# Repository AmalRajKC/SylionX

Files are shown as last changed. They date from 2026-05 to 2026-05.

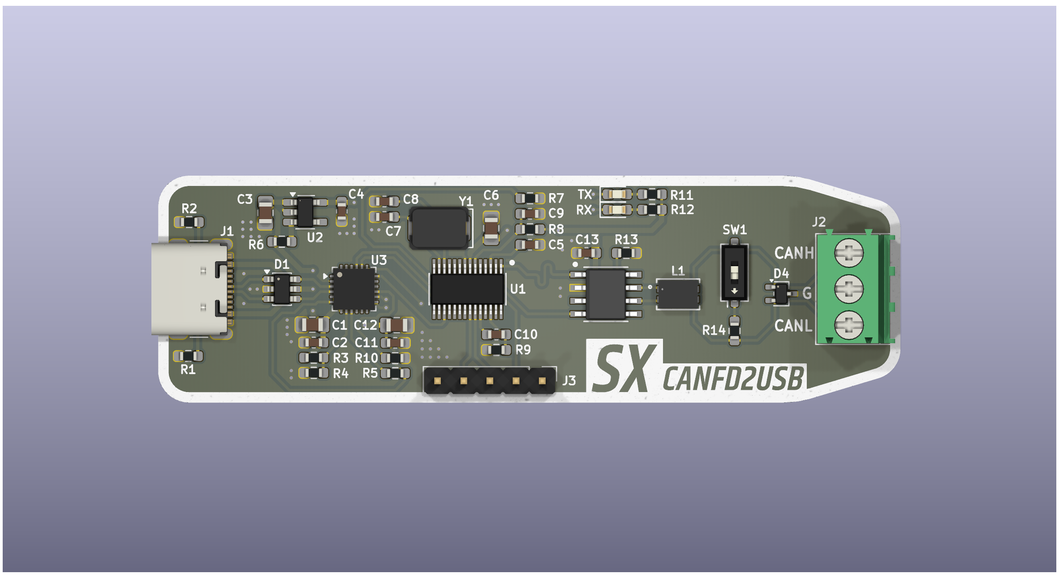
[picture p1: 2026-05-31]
CANFD2USB_Hardware/CANFDtoUSB_V1/CANFDtoUSB_V1.png

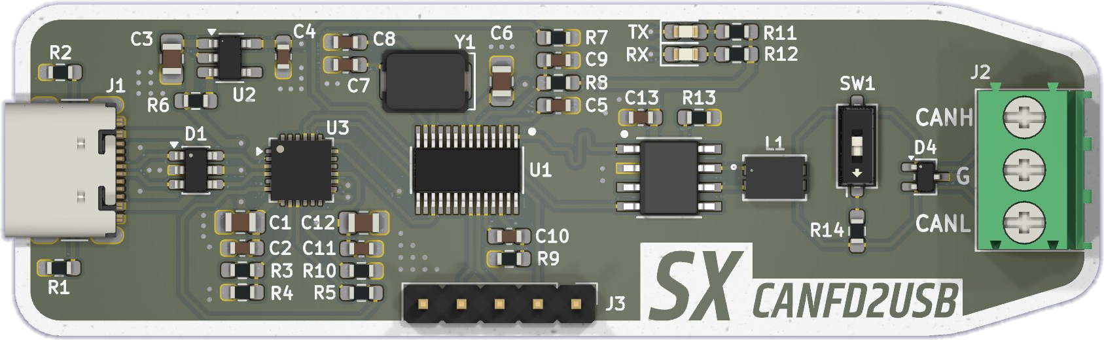
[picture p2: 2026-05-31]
CANFD2USB_Hardware/CANFDtoUSB_V1/CANFDtoUSB_V1nobg.png

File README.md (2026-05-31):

# SylionX — CANFD2USB




An open source USB to CAN FD adapter for real-time CAN bus monitoring, 
diagnostics, and frame injection.

## Repository Structure

| Folder | Contents | License |
|---|---|---|
| `CANFD2USB_Hardware` | KiCad schematics, PCB layout, BOM, gerbers | CERN OHL-S v2 |
| `CANFD2USB_Firmware` | TI MSPM0G3507 C firmware | MIT |
| `CANtrace` | CANtrace Qt6/C++ desktop app | MIT |

## Hardware — CANFD2USB
- Microcontroller: TI MSPM0G3507
- CAN Protocol: Classic CAN + CAN FD (ISO 11898-1)
- Data Rate: Up to 5 Mbps (CAN FD)
- Interface: USB-C (USB 2.0)
- Power: USB powered (5V)
- OS: Windows (Linux planned)

## Getting Started
See [docs/quickstart.md](docs/quickstart.md) for build and setup instructions.

## License
- **Software & Firmware** — [MIT License](LICENSE-MIT.txt)
- **Hardware** — [CERN Open Hardware Licence v2 - Strongly Reciprocal](LICENSE-CERN-OHL-S-v2.txt)

## Issues & Feedback
Found a bug or have a feature request? 
[Open an issue](https://github.com/AmalRajKC/SylionX/issues) — all feedback is welcome.

> **Note:** This repository does not accept pull requests at this time.
> The codebase is open source for transparency and learning — feel free to fork
> and build your own version.

⚠️ Windows SmartScreen may show a warning on first run.
Click "More info" → "Run anyway" to proceed.
This is expected for new unsigned software.
Source code is fully open — you can build from source if preferred.

---
© 2026 SylionX / Amal Raj KC

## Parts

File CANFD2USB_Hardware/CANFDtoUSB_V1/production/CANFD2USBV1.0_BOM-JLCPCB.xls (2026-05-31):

JLCPCB BOM Tool - BOM Matching
BOM name：CANFD2USBV1.0_bom-JLCPCB Assembly Order.xlsx |  |  | Download Time：2026-02-18 17:55:37 |  |  |  | * Our matching results are updated in real-time, but stock and prices may change. If it's been over 24 hours, please re-match before placing your order.
PCB Assembled Qty：5 |  |  | Est. Total Price：51.4846
Your BOM |  |  |  |  | Matched Parts |  |  |  |  |  | Order Information
Top Designator | Bottom Designator | Comment | Footprint | JLCPCB Part # | Matches | Part # | Manufacturer | Footprint | Description | Category | JLCPCB Part # | Product link
C1,C12 |  | 4.7u | 0805 |  | Select by Customer | CL21A475KAQNNNE | Samsung Electro-Mechanics | 0805 | 25V 4.7uF X5R ±10% 0805 Multilayer Ceramic Capacitors MLCC - SMD/SMT ROHS | Multilayer Ceramic Capacitors MLCC - SMD/SMT | C1779 | https://jlcpcb.com/partdetail/2131-CL21A475KAQNNNE/C1779
C3 |  | 1u | 0805 |  | Select by Customer | CL21B105KBFNNNE | Samsung Electro-Mechanics | 0805 | 1uF 50V X7R ±10% 0805 Multilayer Ceramic Capacitors MLCC - SMD/SMT ROHS | Multilayer Ceramic Capacitors MLCC - SMD/SMT | C28323 | https://jlcpcb.com/partdetail/29074-CL21B105KBFNNNE/C28323
C6 |  | 10u | 0805 |  | Select by Customer | CL21A106KOQNNNE | Samsung Electro-Mechanics | 0805 | 10uF 16V X5R ±10% 0805 Multilayer Ceramic Capacitors MLCC - SMD/SMT ROHS | Multilayer Ceramic Capacitors MLCC - SMD/SMT | C1713 | https://jlcpcb.com/partdetail/2065-CL21A106KOQNNNE/C1713
C7,C8 |  | 18p | 0603 |  | Select by Customer | CC0603FRNPO9BN180 | YAGEO | 0603 | 18pF 50V NP0 ±1% 0603 Multilayer Ceramic Capacitors MLCC - SMD/SMT ROHS | Multilayer Ceramic Capacitors MLCC - SMD/SMT | C519484 | https://jlcpcb.com/partdetail/YAGEO-CC0603FRNPO9BN270/C519484
C10,C4,C5,C9 |  | 0.47u | 0603 |  | Select by Customer | CL10B474KA8NNNC | Samsung Electro-Mechanics | 0603 | 25V 470nF X7R ±10% 0603 Multilayer Ceramic Capacitors MLCC - SMD/SMT ROHS | Multilayer Ceramic Capacitors MLCC - SMD/SMT | C1623 | https://jlcpcb.com/partdetail/1975-CL10B474KA8NNNC/C1623
C11,C13,C2 |  | 0.1u | 0603 |  | Select by Customer | CL10B104KB8NNNC | Samsung Electro-Mechanics | 0603 | 100nF 50V X7R ±10% 0603 Multilayer Ceramic Capacitors MLCC - SMD/SMT ROHS | Multilayer Ceramic Capacitors MLCC - SMD/SMT | C1591 | https://jlcpcb.com/partdetail/1943-CL10B104KB8NNNC/C1591
D1 |  | USBLC6-2SC6 | SOT-23-6 |  | Select by System | USBLC6-2SC6 | TECH PUBLIC | SOT-23-6 | -55℃~+125℃ 0.35pF 12V 150W 2 5V 6A 6V 80nA ESD IEC 61000-4-2、IEC 61000-4-5、IEC 61000-4-4 Unidirectional SOT-23-6 ESD and Surge Protection (TVS/ESD) ROHS | ESD And Surge Protection (TVS/ESD) | C2827654 | https://jlcpcb.com/partdetail/TECHPUBLIC-USBLC62SC6/C2827654
D2,D3 |  | TXLED | 0603 |  | Select by Customer | KT-0603W | Hubei KENTO Elec | 0603 | 100mW 120° 2.6V~3.1V 360mcd 5mA Discrete Diode Top-mount White Yellow Lens 0603 LED Indication - Discrete ROHS | LED Indication - Discrete | C2290 | https://jlcpcb.com/partdetail/Hubei_KENTOElec-KT0603W/C2290
D4 |  | CANESD | SOT-323_SC-70 |  | Select by Customer | SP0502BAHTG | Littelfuse | SOT-23 | -40℃~+125℃ 100nA 2 30pF 5.5V 8.5V IEC 61000-4-2 TVS Unidirectional SOT-23 ESD and Surge Protection (TVS/ESD) ROHS | ESD And Surge Protection (TVS/ESD) | C207261 | https://jlcpcb.com/partdetail/Littelfuse-SP0502BAHTG/C207261
J1 |  | USB4105 | USB4105 |  | Select by Customer | USB4105-GF-A-120 | Global Connector Technology | SMD | -40℃~+85℃ 1 16P 48V 5A Black Female Type-C USB 2.0 SMD USB Connectors ROHS | USB Connectors | C5184243 | https://jlcpcb.com/partdetail/5849584-USB4105_GF_A120/C5184243
L1 |  | ACT1210 | ACT1210D-101-2P-TL00 |  | Select by Customer | ACT1210D-101-2P-TL00 | TDK | SMD-4P,3.2x2.5mm | -40℃~+150℃ 100uH@100kHz 10MΩ 115mA 2 3Ω 5.1kΩ@10MHz 80V SMD-4P,3.2x2.5mm Common Mode Filters ROHS | Common Mode Filters | C3039743 | https://jlcpcb.com/partdetail/TDK-ACT1210D_101_2PTL00/C3039743
R1,R10,R2,R8 |  | 5.1K | 0603 |  | Select by Customer | RC0603JR-075K1L | YAGEO | 0603 | -55℃~+155℃ 100mW 5.1kΩ 75V Thick Film Resistor ±100ppm/℃ ±5% 0603 Chip Resistor - Surface Mount ROHS | Chip Resistor - Surface Mount | C14677 | https://jlcpcb.com/partdetail/YAGEO-RC0603JR075K1L/C14677
R3 |  | 22.1K | 0603 |  | Select by Customer | RC0603FR-0722K1L | YAGEO | 0603 | -55℃~+155℃ 100mW 22.1kΩ 75V Thick Film Resistor ±1% ±100ppm/℃ 0603 Chip Resistor - Surface Mount ROHS | Chip Resistor - Surface Mount | C137768 | https://jlcpcb.com/partdetail/YAGEO-RC0603FR0722K1L/C137768
R4 |  | 47.5K | 0603 |  | Select by Customer | RC0603FR-0747K5L | YAGEO | 0603 | -55℃~+155℃ 100mW 47.5kΩ 75V Thick Film Resistor ±1% ±100ppm/℃ 0603 Chip Resistor - Surface Mount ROHS | Chip Resistor - Surface Mount | C137715 | https://jlcpcb.com/partdetail/YAGEO-RC0603FR0747K5L/C137715
R5,R6 |  | 1K | 0603 |  | Select by Customer | RC0603JR-071KL | YAGEO | 0603 | -55℃~+155℃ 100mW 1kΩ 75V Thick Film Resistor ±100ppm/℃ ±5% 0603 Chip Resistor - Surface Mount ROHS | Chip Resistor - Surface Mount | C14676 | https://jlcpcb.com/partdetail/YAGEO-RC0603JR071KL/C14676
R7 |  | 100K | 0603 |  | Select by Customer | RT0603BRD07100KL | YAGEO | 0603 | -55℃~+155℃ 100kΩ 100mW 75V Thin Film Resistor ±0.1% ±25ppm/℃ 0603 Chip Resistor - Surface Mount ROHS | Chip Resistor - Surface Mount | C122538 | https://jlcpcb.com/partdetail/YAGEO-RT0603BRD07100KL/C122538
R11,R12,R14 |  | 120R | 0603 |  | Select by Customer | RC0603FR-07120RL | YAGEO | 0603 | -55℃~+155℃ 100mW 120Ω 75V Thick Film Resistor ±1% ±100ppm/℃ 0603 Chip Resistor - Surface Mount ROHS | Chip Resistor - Surface Mount | C114640 | https://jlcpcb.com/partdetail/YAGEO-RC0603FR07120RL/C114640
R13,R9 |  | 0R | 0603 |  | Select by Customer | RC0603JR-070RL | YAGEO | 0603 | -55℃~+155℃ 0Ω 100mW 75V Thick Film Resistor ±5% 0603 Chip Resistor - Surface Mount ROHS | Chip Resistor - Surface Mount | C95177 | https://jlcpcb.com/partdetail/YAGEO-RC0603JR070RL/C95177
SW1 |  | SPST | CHS-01A |  | Select by Customer | CHS-01A1 | Nidec | SMD,P=2.54mm | -40℃~+85℃ 1 100mA 2,000 cycles 2.54mm 6V J-Lead SPST Slide, Recessed SMD,P=2.54mm DIP Switches ROHS | DIP Switches | C3312106 | https://jlcpcb.com/partdetail/Nidec-CHS01A1/C3312106
U1 |  | MSMP0G3507 | VSSOP28_DGS_TEX |  | Select by Customer | MSPM0G3507SDGS28R | Texas Instruments | VSSOP-28 | -40℃~+125℃ 1.62V~3.6V 128KB 24 32 Bit 32KB 80MHz ARM Cortex-M0+ Built-in+External FLASH VSSOP-28 Microcontrollers (MCU/MPU/SOC) ROHS | Global Sourcing Parts | C33814868 | https://jlcpcb.com/partdetail/35547499-MSPM0G3507SDGS28R/C33814868
U2 |  | TLV78533PDBVR | SOT-23-5_HandSoldering |  | Select by System | TLV78533PDBVR | Texas Instruments | SOT-23-5 | SOT-23-5 Voltage Regulators - Linear, Low Drop Out (LDO) Regulators ROHS |  | C49256224 | https://jlcpcb.com/partdetail/TexasInstruments-TLV78533PDBVR/C49256224
U3 |  | CP2102N | QFN-24-1EP |  | Select by Customer | CP2102N-A02-GQFN24R | SKYWORKS/SILICON LABS | QFN-24-EP(4x4) | -40℃~+85℃@(Ta) 1.3uA 3V~3.6V 9.5mA USB 2.0 USB to UART QFN-24-EP(4x4) USB Converters ROHS | USB Converters | C969151 | https://jlcpcb.com/partdetail/1058352-CP2102N_A02GQFN24R/C969151
U4 |  | TCAN3413DR | SOIC8_D_TEX |  | Select by System | TCAN3413DR | Texas Instruments | SOIC-8 | -40℃~+125℃ 3V~3.6V 42mA 4uA 5Mbps CAN FD Transceiver SOIC-8 CAN Transceivers ROHS | CAN Transceivers | C22433320 | https://jlcpcb.com/partdetail/TexasInstruments-TCAN3413DR/C22433320
Y1 |  | ABM3 | 2Pin_5.0x3.2mm |  | Select by Customer | ABM3-8.000MHZ-D2Y-T | Abracon LLC | SMD5032-2P | -40℃~+85℃ 140Ω 18pF 8MHz Crystal Oscillator ±20ppm ±30ppm SMD5032-2P Crystals ROHS | Crystals | C144380 | https://jlcpcb.com/partdetail/AbraconLLC-ABM3_8_000MHZ_D2YT/C144380
J2 |  | DNP | DNP |  | No matches | No Part Selected
J3 |  | DNP | DNP |  | No matches | No Part Selected

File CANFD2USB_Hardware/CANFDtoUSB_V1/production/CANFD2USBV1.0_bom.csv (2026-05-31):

Designator | Footprint | Quantity | Value | LCSC Part #
C1, C12 | 0805 | 2 | 4.7u
C10, C4, C5, C9 | 0603 | 4 | 0.47u
C11, C13, C2 | 0603 | 3 | 0.1u
C3 | 0805 | 1 | 1u
C6 | 0805 | 1 | 10u
C7, C8 | 0603 | 2 | 27p
D1 | SOT-23-6 | 1 | USBLC6-2SC6
D2, D3 | 0603 | 2 | TX LED
D4 | SOT-323_SC-70 | 1 | CANESD
J1 | USB4105 | 1 | USB4105
J2 | DNP | 1 | DNP
J3 | DNP | 1 | DNP
L1 | ACT1210D-101-2P-TL00 | 1 | ACT1210
R1, R10, R2, R8 | 0603 | 4 | 5.1K
R11, R12, R14 | 0603 | 3 | 120R
R13, R9 | 0603 | 2 | 0R
R3 | 0603 | 1 | 22.1K
R4 | 0603 | 1 | 47.5K
R5, R6 | 0603 | 2 | 1K
R7 | 0603 | 1 | 100K
SW1 | CHS-01A | 1 | SPST
U1 | VSSOP28_DGS_TEX | 1 | MSMP0G3507
U2 | SOT-23-5_HandSoldering | 1 | TLV78533PDBVR
U3 | QFN-24-1EP | 1 | CP2102N
U4 | SOIC8_D_TEX | 1 | TCAN3413DR
Y1 | 2Pin_5.0x3.2mm | 1 | ABM3

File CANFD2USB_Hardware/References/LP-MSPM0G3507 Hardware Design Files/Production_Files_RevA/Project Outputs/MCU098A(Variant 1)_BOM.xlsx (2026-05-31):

Fitted | Description | Designator | PartNumber | Quantity | Manufacturer | PackageReference | Value | Alternate Manufacturer | Alternate PartNumber
Fitted | Printed Circuit Board | !PCB1 | MCU098 | 1 | Any
Fitted | CAP, CERM, 10 uF, 6.3 V, +/- 20%, X5R, 0603 | C1 | GRM188R60J106ME84 | 1 | MuRata | 0603 | 10uF
Fitted | CAP, CERM, 0.1 uF, 50 V, +/- 20%, X5R, 0402 | C2 | GRM155R61H104ME14D | 1 | MuRata | 0402 | 0.1uF
Fitted | CAP, CERM, 0.47 uF, 6.3 V, +/- 10%, X5R, 0402 | C3 | GRM155R60J474KE19D | 1 | MuRata | 0402 | 0.47uF
Fitted | CAP, CERM, 47 pF, 25 V, +/- 5%, C0G/NP0, 0402 | C5 | GRM1555C1E470JA01D | 1 | MuRata | 0402 | 47pF
Fitted | CAP, CERM, 0.01 uF, 16 V, +/- 10%, X5R, 0402 | C6 | GRM155R61C103KA01D | 1 | MuRata | 0402 | 0.01uF
Fitted | CAP, CERM, 1 uF, 25 V, +/- 10%, X5R, 0603 | C8 | C1608X5R1E105K080AC | 1 | TDK | 0603 | 1uF
Fitted | CAP, CERM, 22 pF, 50 V, +/- 5%, C0G/NP0, 0402 | C9, C10, C11, C12 | GRM1555C1H220JA01D | 4 | MuRata | 0402 | 22pF
Fitted | CAP, CERM, 0.1 uF, 6.3 V, +/- 10%, X7R, 0402 | C13, C17, C18, C20, C24, C27, C28, C33, C38, C39, C44 | GRM155R70J104KA01D | 11 | MuRata | 0402 | 0.1uF
Fitted | CAP, CERM, 0.01 uF, 25 V, +/- 10%, X7R, 0402 | C14, C15, C16, C22, C26 | GRM155R71E103KA01D | 5 | MuRata | 0402 | 0.01uF
Fitted | CAP, CERM, 1 uF, 25 V, +/- 10%, X5R, 0402 | C19, C21, C25, C55 | C1005X5R1E105K050BC | 4 | TDK | 0402 | 1uF
Fitted | CAP, CERM, 2.2 uF, 6.3 V, +/- 10%, X5R, 0402 | C23, C56 | GRM155R60J225KE95D | 2 | MuRata | 0402 | 2.2uF
Fitted | CAP, CERM, 12 pF, 50 V, +/- 5%, C0G/NP0, 0402 | C29, C30 | GRM1555C1H120JA01D | 2 | MuRata | 0402 | 12pF
Fitted | CAP, CERM, 33 pF, 50 V, +/- 5%, C0G/NP0, 0402 | C31, C34 | GRM1555C1H330JA01D | 2 | MuRata | 0402 | 33pF
Fitted | CAP, TA, 4.7 uF, 16 V, +/- 10%, 4 ohm, SMD | C32, C36 | TAJA475K016RNJ | 2 | AVX | 3216-18 | 4.7uF
Fitted | CAP, CERM, 1000 pF, 50 V, +/- 10%, X7R, AEC-Q200 Grade 1, 0402 | C35 | GCM155R71H102KA37D | 1 | MuRata | 0402 | 1000pF
Fitted | CAP, CERM, 4.7 uF, 16 V, +/- 10%, X5R, 0603 | C37, C43 | GRM188R61C475KAAJ | 2 | MuRata | 0603 | 4.7uF
Fitted | CAP, CERM, 47 uF, 6.3 V, +/- 20%, X5R, 0603 | C40 | GRM188R60J476ME15D | 1 | MuRata | 0603 | 47uF
Fitted | CAP, CERM, 0.22 uF, 16 V, +/- 10%, X7R, 0402 | C41, C42 | GRM155R71C224KA12D | 2 | MuRata | 0402 | 0.22uF
Fitted | CAP, CERM, 82 pF, 50 V, +/- 10%, C0G/NP0, 0603 | C47 | C0603C820K5GACTU | 1 | Kemet | 0603 | 82pF
Fitted | CAP, CERM, 2.2 uF, 10 V, +/- 10%, X5R, 0603 | C53 | C0603C225K8PACTU | 1 | Kemet | 0603 | 2.2uF
Fitted | CAP, CERM, 3300 pF, 50 V, +/- 10%, X7R, 0402 | C54 | GRM155R71H332KA01D | 1 | MuRata | 0402 | 3300pF
Fitted | Photodiode PIN Chip 910nm Automotive 2-Pin Case 0805(2012Metric) T/R | D1 | VEMD4110X01 | 1 | Vishay | 0805
Fitted | Diode, Schottky, 40 V, 0.12 A, AEC-Q101, SOT-323 | D2, D3 | BAS40-05W,115 | 2 | Nexperia | SOT-323 | 40V
Fitted | Fiducial mark. There is nothing to buy or mount. | FID1, FID2, FID3 | N/A | 3 | N/A | N/A
Fitted | Spacer Support, Nylon 66 | H1, H2 | MAE-10 | 2 | Kang Yang | Spacer Nylon Support
Fitted | 2.7-4V Dual In/Single Out MOSFET, 0.5A Main/0.1A Aux Input, Act-Low Enable, Comm. Temp., DBV0005A (SOT-23-5) | IC1 | TPS2102DBVR | 1 | Texas Instruments | DBV0005A |  | Texas Instruments | TPS2102DBVT
Fitted | Low-Capacitance + / - 15 kV ESD Protection Array for High-Speed Data Interfaces, 6 Channels, -40 to +85 degC, 8-pin UQFN (RSE), Green (RoHS & no Sb/Br) | IC2, U1 | TPD6E004RSER | 2 | Texas Instruments | RSE0008A
Fitted | ESD-Protection Array for High-Speed Data Interfaces, 4 Channels, -40 to +85 degC, 6-pin SON (DRY), Green (RoHS & no Sb/Br) | IC3 | TPD4E004DRYR | 1 | Texas Instruments | DRY0006A
Fitted | 500mA, Adjustable, Low Quiescent Current, Low-Noise, High-PSRR, Single-Output LDO Regulator, DRB0008A (VSON-8) | IC4 | TPS73533DRBT | 1 | Texas Instruments | DRB0008A
Fitted | Precision Micropower Shunt Voltage Reference, 0.5% accuracy, 2.5 V, 15 ppm / degC, 15 mA, -40 to 85 degC, 5-pin SC70 (DCK), Green (RoHS & no Sb/Br) | IC5 | LM4040C25IDCKR | 1 | Texas Instruments | DCK0005A
Fitted | Receptacle, 2.54mm, 10x2, Tin, TH | J1/J3, J2/J4 | SSQ-110-03-T-D | 2 | Samtec | 10x2 Receptacle |  | Major League Electronics | CRD-081413-A-G
Fitted | Header, 100mil, 2x1, Tin, TH | J4, J5, J6, J7, J8, J13, J16, J17, J18 | 90120-0122 | 9 | Molex | Header 2x1
Fitted | Header, 100mil, 3x1, Tin, TH | J9, J10, J11, J14, J15, J19, J20, J21, J22 | PEC03SAAN | 9 | Sullins Connector Solutions | Header, 3 PIN, 100mil, Tin
Fitted | Header, 2.54mm, 9x2, Tin, TH | J101 | PEC09DAAN | 1 | Sullins Connector Solutions | Header, 2.54mm, 9x2, TH
Fitted | Header(Shrouded), 1.27mm, 5x2, Gold, SMT | J102, J103 | FTSH-105-01-L-DV-K | 2 | Samtec | Header(Shrouded), 1.27mm, 5x2, SMT
Fitted | Inductor, Wirewound, Ceramic, 2.2 uH, 0.89 A, 0.13 ohm, SMD | L1 | CBC2518T2R2M | 1 | Taiyo Yuden | 2.5x1.8x1.8mm | 2.2uH
Fitted | LED, Red, SMD | LED1, LED101 | BR1111C-TR | 2 | Stanley Electric Co., LTD | 1.6x0.8mm | Red
Fitted | LED, RGB, SMD | LED2 | 19-337/R6GHBHC-A01/2T | 1 | Everlight | 1.6x1.6mm | Rgb
Fitted | LED, Green, SMD | LED102 | LTST-C190GKT | 1 | Lite-On | 1.6x0.8x0.8mm | Green
Fitted | Mixed-Signal Microcontrollers With CAN-FD Interface LQFP64 | MSP1 | MSPM0G3507SPM | 1 | Texas Instruments | LQFP64
Fitted | RES, 2.37 M, 1%, 0.1 W, 0603 | R1 | CRCW06032M37FKEA | 1 | Vishay-Dale | 0603 | 2.37Meg
Fitted | RES, 47 k, 5%, 0.063 W, 0402 | R2, R14 | CRCW040247K0JNED | 2 | Vishay-Dale | 0402 | 47k
Fitted | RES, 0, 5%, 0.1 W, 0603 | R3, R52, R55, R57, R58, R62, R63, R64, R65, R69, R71, R73, R75, R76, R77, R78, R79, R80, R81, R82, R83, R84, R86, R89 | RC0603JR-070RL | 24 | Yageo | 0603 | 0
Fitted | RES, 470, 5%, 0.063 W, 0402 | R4, R29, R30, R48 | CRCW0402470RJNED | 4 | Vishay-Dale | 0402 | 470
Fitted | RES, 220, 5%, 0.063 W, 0402 | R5 | CRCW0402220RJNED | 1 | Vishay-Dale | 0402 | 220
Fitted | RES, 330, 5%, 0.063 W, 0402 | R6, R7 | CRCW0402330RJNED | 2 | Vishay-Dale | 0402 | 330
Fitted | Res Thin Film 0402 100K Ohm 0.1% 1/16W ±25ppm/°C Molded SMD SMD Punched Carrier T/R | R8 | ERA-2AEB104X | 1 | Panasonic | 0402
Fitted | RES, 4.7 k, 5%, 0.1 W, 0603 | R12, R16 | RC0603JR-074K7L | 2 | Yageo | 0603 | 4.7k
Fitted | RES, 270, 5%, 0.063 W, 0402 | R13, R19 | CRCW0402270RJNED | 2 | Vishay-Dale | 0402 | 270
Fitted | RES, 2.2 k, 5%, 0.1 W, 0603 | R18, R21 | RC0603JR-072K2L | 2 | Yageo | 0603 | 2.2k
Fitted | RES, 0, 5%, 0.063 W, 0402 | R23 | RC0402JR-070RL | 1 | Yageo America | 0402 | 0
Fitted | RES, 1.0 k, 5%, 0.063 W, 0402 | R24, R25, R26, R34 | CRCW04021K00JNED | 4 | Vishay-Dale | 0402 | 1.0k
Fitted | RES, 100, 5%, 0.063 W, AEC-Q200 Grade 0, 0402 | R28 | CRCW0402100RJNED | 1 | Vishay-Dale | 0402 | 100
Fitted | RES, 10 k, 5%, 0.063 W, 0402 | R31, R91, R92 | CRCW040210K0JNED | 3 | Vishay-Dale | 0402 | 10k
Fitted | RES, 4.87 k, 1%, 0.063 W, AEC-Q200 Grade 0, 0402 | R32 | CRCW04024K87FKED | 1 | Vishay-Dale | 0402 | 4.87k
Fitted | RES, 100, 5%, 0.063 W, 0402 | R33 | CRCW0402100RJNED | 1 | Vishay-Dale | 0402 | 100
Fitted | RES, 51, 5%, 0.063 W, AEC-Q200 Grade 0, 0402 | R35 | CRCW040251R0JNED | 1 | Vishay-Dale | 0402 | 51
Fitted | RES, 220 k, 1%, 0.0625 W, 0402 | R36, R37, R43, R44, R51, R54, R88 | RC0402FR-07220KL | 7 | Yageo America | 0402 | 220k
Fitted | RES, 3.30 k, 1%, 0.1 W, AEC-Q200 Grade 0, 0402 | R38, R85 | ERJ-2RKF3301X | 2 | Panasonic | 0402 | 3.30k
Fitted | RES, 2.20 k, 1%, 0.063 W, 0402 | R39 | CRCW04022K20FKED | 1 | Vishay-Dale | 0402 | 2.20k
Fitted | RES, 6.81 k, 1%, 0.063 W, 0402 | R40 | CRCW04026K81FKED | 1 | Vishay-Dale | 0402 | 6.81k
Fitted | RES, 4.7 k, 5%, 0.063 W, 0402 | R41, R42 | CRCW04024K70JNED | 2 | Vishay-Dale | 0402 | 4.7k
Fitted | RES, 47.0 k, 1%, 0.0625 W, 0402 | R45, R46, R49 | RC0402FR-0747KL | 3 | Yageo America | 0402 | 47.0k
Fitted | RES, 820, 1%, 0.063 W, 0402 | R47 | RC0402FR-07820RL | 1 | Yageo America | 0402 | 820
Fitted | RES, 10.0 k, 0.1%, 0.1 W, AEC-Q200 Grade 0, 1.6x0.8mm | R56 | ERA3ARB103V | 1 | Panasonic | 1.6x0.8mm | 10.0k
Fitted | RES, 100, 1%, 0.1 W, 0603 | R72 | RC0603FR-07100RL | 1 | Yageo | 0603 | 100
Fitted | RES, 330 k, 1%, 0.0625 W, 0402 | R87 | RC0402FR-07330KL | 1 | Yageo America | 0402 | 330k
Fitted | RES, 1.00 M, 1%, 0.063 W, 0402 | R90 | CRCW04021M00FKED | 1 | Vishay-Dale | 0402 | 1.00Meg
Fitted | Thermistor, DEC0002A (X1SON-2) | RT1 | TMP6131DECT | 1 | Texas Instruments | DEC0002A |  | Texas Instruments | TMP6131DECR
Fitted | Switch, SPST, 0.05 A, 12 VDC, SMD | S1, S2, S3 | 1188E-1K2-V-TR | 3 | Diptronics | 7.8x3.5mm
Fitted | Shunt, 100mil, Gold plated, Black | SH-J1 | SNT-100-BK-G | 1 | Samtec | Shunt | J101: 1-2 | 3M | 969102-0000-DA
Fitted | Shunt, 100mil, Gold plated, Black | SH-J2 | SNT-100-BK-G | 1 | Samtec | Shunt | J101: 3-4 | 3M | 969102-0000-DA
Fitted | Shunt, 100mil, Gold plated, Black | SH-J3 | SNT-100-BK-G | 1 | Samtec | Shunt | J101: 5-6 | 3M | 969102-0000-DA
Fitted | Shunt, 100mil, Gold plated, Black | SH-J4 | SNT-100-BK-G | 1 | Samtec | Shunt | J101: 7-8 | 3M | 969102-0000-DA
Fitted | Shunt, 100mil, Gold plated, Black | SH-J5 | SNT-100-BK-G | 1 | Samtec | Shunt | J101: 9-10 | 3M | 969102-0000-DA
Fitted | Shunt, 100mil, Gold plated, Black | SH-J6 | SNT-100-BK-G | 1 | Samtec | Shunt | J101: 11-12 | 3M | 969102-0000-DA
Fitted | Shunt, 100mil, Gold plated, Black | SH-J7 | SNT-100-BK-G | 1 | Samtec | Shunt | J101: 12-13 | 3M | 969102-0000-DA
Fitted | Shunt, 100mil, Gold plated, Black | SH-J8 | SNT-100-BK-G | 1 | Samtec | Shunt | J101: 15-16 | 3M | 969102-0000-DA
Fitted | Shunt, 100mil, Gold plated, Black | SH-J9 | SNT-100-BK-G | 1 | Samtec | Shunt | J101: 17-18 | 3M | 969102-0000-DA
Fitted | Shunt, 100mil, Gold plated, Black | SH-J10, SH-J11 | SNT-100-BK-G | 2 | Samtec | Shunt | J14: 1-2 | 3M | 969102-0000-DA
Fitted | Shunt, 100mil, Gold plated, Black | SH-J12 | SNT-100-BK-G | 1 | Samtec | Shunt | J16: 1-2 | 3M | 969102-0000-DA
Fitted | Shunt, 100mil, Gold plated, Black | SH-J13 | SNT-100-BK-G | 1 | Samtec | Shunt | J17: 1-2 | 3M | 969102-0000-DA
Fitted | Shunt, 100mil, Gold plated, Black | SH-J14 | SNT-100-BK-G | 1 | Samtec | Shunt | J18: 1-2 | 3M | 969102-0000-DA
Fitted | Shunt, 100mil, Gold plated, Black | SH-J15 | SNT-100-BK-G | 1 | Samtec | Shunt | J5: 1-2 | 3M | 969102-0000-DA
Fitted | Shunt, 100mil, Gold plated, Black | SH-J16 | SNT-100-BK-G | 1 | Samtec | Shunt | J6: 1-2 | 3M | 969102-0000-DA
Fitted | Shunt, 100mil, Gold plated, Black | SH-J17 | SNT-100-BK-G | 1 | Samtec | Shunt | J7: 1-2 | 3M | 969102-0000-DA
Fitted | Shunt, 100mil, Gold plated, Black | SH-J18 | SNT-100-BK-G | 1 | Samtec | Shunt | J8: 1-2 | 3M | 969102-0000-DA
Fitted | Shunt, 100mil, Gold plated, Black | SH-J19 | SNT-100-BK-G | 1 | Samtec | Shunt | J9: 1-2 | 3M | 969102-0000-DA
Fitted | Shunt, 100mil, Gold plated, Black | SH-J20 | SNT-100-BK-G | 1 | Samtec | Shunt | J13: 1-2 | 3M | 969102-0000-DA
Fitted | Shunt, 100mil, Gold plated, Black | SH-J21 | SNT-100-BK-G | 1 | Samtec | Shunt | J15: 1-2 | 3M | 969102-0000-DA
Fitted | Shunt, 100mil, Gold plated, Black | SH-J22 | SNT-100-BK-G | 1 | Samtec | Shunt | J19: 1-2 | 3M | 969102-0000-DA
Fitted | Shunt, 100mil, Gold plated, Black | SH-J23 | SNT-100-BK-G | 1 | Samtec | Shunt | J20: 1-2 | 3M | 969102-0000-DA
Fitted | Shunt, 100mil, Gold plated, Black | SH-J24 | SNT-100-BK-G | 1 | Samtec | Shunt | J21: 1-2 | 3M | 969102-0000-DA
Fitted | Shunt, 100mil, Gold plated, Black | SH-J25 | SNT-100-BK-G | 1 | Samtec | Shunt | J22: 1-2 | 3M | 969102-0000-DA
Fitted | MOSFET, P-CH, -20 V, -0.82 A, SOT-323 | T1 | DMG1013UW-7 | 1 | Diodes Inc. | SOT-323 | -20V | None
Fitted | Transistor, NPN, 45 V, 0.1 A, SOT-323 | T2 | BC850CW,115 | 1 | NXP Semiconductor | SOT-323 | 45 V
Fitted | 50 MHz, Low-Noise Single-Supply Rail-to-Rail Operational Amplifier, 2.2 to 5.5 V, -40 to 125 degC, 8-pin SOIC (D8), Green (RoHS & no Sb/Br) | U2 | OPA2365AIDR | 1 | Texas Instruments | D0008A
Fitted | Cable, USB-A to micro USB-B, 0.3 m | USB1 | AK67421-0.3 | 1 | Assman WSW
Fitted | Receptacle, USB 2.0, Micro B, 5 Position, R/A, SMT | USB2 | 1051640001 | 1 | Molex | Receptacle, USB 2.0, Micro B, 5 Pos, 0.65mm Pitch, R/A, SMT
Fitted | MSP432E401YTPDT, PDT0128A (TQFP-128) | XDS1 | MSP432E401YTPDTR | 1 | Texas Instruments | PDT0128A |  | Texas Instruments | MSP432E401YTPDT
Fitted | MSP430G2x52, MSP430G2x12 Mixed Signal Microcontroller, RSA0016B (VQFN-16) | XDS2 | MSP430G2452IRSA16R | 1 | Texas Instruments | RSA0016B |  |  | MSP430G2452IRSA16T
Fitted | Crystal, 32.768 KHz, 12.5 pF, SMD | Y1 | X1A0001410014 | 1 | Epson | SMD, 2-Leads, Body 3.2x1.5mm
Fitted | Crystal 40MHz ±10ppm (Tol) ±20ppm (Stability) 12pF FUND 40Ohm 4-Pin Mini-CSMD T/R | Y2 | X1E0000210179 | 1 | Seiko Epson | TSX-3225
Fitted | Crystal, 16 MHz, 8pF, SMD | Y3 | NX3225GA-16.000M-STD-CRG-1 | 1 | NDK | 3.2x0.75x2.5mm

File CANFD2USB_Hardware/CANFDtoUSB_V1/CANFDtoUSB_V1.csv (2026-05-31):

Reference | Value | Footprint | Product Link | Purchase Link | Part Number | Description
C1,C12 | 4.7u | Capacitor_SMD:C_0805_2012Metric_Pad1.18x1.45mm_HandSolder |  | https://in.element14.com/murata/grm21br71c475ke51k/cap-4-7uf-16v-mlcc-0805/dp/3790443 | GRM21BR71C475KE51K | Unpolarized capacitor, small symbol
C2,C11,C13 | 0.1u | Capacitor_SMD:C_0603_1608Metric_Pad1.08x0.95mm_HandSolder |  | https://in.element14.com/yageo/cc0603kpx7r7bb104/cap-0-1uf-16v-mlcc-0603/dp/3764501 | CC0603KPX7R7BB104 | Unpolarized capacitor, small symbol
C3 | 1u | Capacitor_SMD:C_0805_2012Metric_Pad1.18x1.45mm_HandSolder |  | https://in.element14.com/samsung-electro-mechanics/cl21b105kofnnnf/cap-mlcc-1uf-x7r-16v-0805/dp/4748630 | CL21B105KOFNNNF | Unpolarized capacitor, small symbol
C4,C5,C9,C10 | 0.47u | Capacitor_SMD:C_0603_1608Metric_Pad1.08x0.95mm_HandSolder |  | https://in.element14.com/samsung-electro-mechanics/cl10b474ko8nnnc/cap-0-47uf-16v-mlcc-0603/dp/3013435 | CL10B474KO8NNNC | Unpolarized capacitor, small symbol
C6 | 10u | Capacitor_SMD:C_0805_2012Metric_Pad1.18x1.45mm_HandSolder |  | https://in.element14.com/samsung-electro-mechanics/cl21a106koqnnnf/cap-mlcc-10uf-x5r-16v-0805/dp/4539078 | CL21A106KOQNNNF | Unpolarized capacitor, small symbol
C7,C8 | 18p | Capacitor_SMD:C_0603_1608Metric_Pad1.08x0.95mm_HandSolder |  | https://in.element14.com/yageo/cc0603grnpo9bn180/cap-18pf-50v-mlcc-0603/dp/3764440 | CC0603GRNPO9BN180 | Unpolarized capacitor, small symbol
D1 | USBLC6-2SC6 | Package_TO_SOT_SMD:SOT-23-6 |  | https://jlcpcb.com/partdetail/STMicroelectronics-USBLC62P6/C15999 | USBLC6-2P6 | Very low capacitance ESD protection diode, 2 data-line, SOT-23-6
D2,D3 | TX LED | LED_SMD:LED_0603_1608Metric_Pad1.05x0.95mm_HandSolder |  | https://jlcpcb.com/partdetail/EverlightElec-19_217_BHC_ZL1M2RY6T/C2986058 | 19-217/BHC-ZL1M2RY/6T | Light emitting diode
D4 | CANESD | Package_TO_SOT_SMD:SOT-323_SC-70 |  | https://in.element14.com/littelfuse/sp0502bahtg/diode-tvs-aval-2-ch-sot23/dp/1827631 | SP0502BAHTG | TVS Diode Array, 5.5V Standoff, 2 Channels, SC-70 package
J1 | USB4105 | Connector_USB:USB_C_Receptacle_GCT_USB4105-xx-A_16P_TopMnt_Horizontal |  | https://in.element14.com/gct-global-connector-technology/usb4105-gf-a-120/usb-conn-2-0-type-c-r-a-rcpt-16pos/dp/3777660 | USB4105-GF-A-120 | USB 2.0-only 16P Type-C Receptacle connector
J2 | CAN Terminal | TerminalBlock_Phoenix:TerminalBlock_Phoenix_PT-1,5-3-3.5-H_1x03_P3.50mm_Horizontal |  | https://jlcpcb.com/partdetail/AmphenolICC-YO0301500000G/C2683167 | YO0301500000G | Generic screw terminal, single row, 01x03, script generated (kicad-library-utils/schlib/autogen/connector/)
J3 | Conn_01x05_Pin | Connector_PinHeader_2.54mm:PinHeader_1x05_P2.54mm_Vertical |  |  |  | Generic connector, single row, 01x05, script generated
JP1 | 3V3_LDO_TTL_Jumper | Jumper:SolderJumper-3_P1.3mm_Open_RoundedPad1.0x1.5mm_NumberLabels |  |  |  | Solder Jumper, 3-pole, open
L1 | ACT1210 | ACT1210D:ACT1210D-101-2P-TL00 |  | https://in.element14.com/tdk/act1210d-101-2p-tl00/common-mode-choke-100uh-115a/dp/4125606 | ACT1210D-101-2P-TL00 | Common Mode Choke, ACT Series, 100 µH, 115 A, 3.2 mm x 2.5 mm x 2.5 mm
R1,R2,R8,R10 | 5.1K | Resistor_SMD:R_0603_1608Metric_Pad0.98x0.95mm_HandSolder |  | https://robu.in/product/rc0603fr-135k1l-yageo-0-1w-thick-film-resistors-%C2%B1100ppm-%E2%84%83-%C2%B11-5-1k%CF%89-0603-chip-resistor-surface-mount-rohs/ | RC0603FR-135K1L | SMD Chip Resistor, 5.1 kohm, ± 1%, 100 mW, 0603 [1608 Metric], Thick Film, General Purpose
R3 | 22.1K | Resistor_SMD:R_0603_1608Metric_Pad0.98x0.95mm_HandSolder |  | https://in.element14.com/yageo/rc0603fr-0722k1l/res-22k1-1-0-1w-0603-thick-film/dp/3495773RL | RC0603FR-0722K1L | SMD Chip Resistor, 5.1 kohm, ± 1%, 100 mW, 0603 [1608 Metric], Thick Film, General Purpose
R4 | 47.5K | Resistor_SMD:R_0603_1608Metric_Pad0.98x0.95mm_HandSolder |  | https://in.element14.com/yageo/rc0603fr-0747k5l/res-47k5-1-0-1w-0603-thick-film/dp/3495852 | RC0603FR-0747K5L | SMD Chip Resistor, 5.1 kohm, ± 1%, 100 mW, 0603 [1608 Metric], Thick Film, General Purpose
R5,R6 | 1K | Resistor_SMD:R_0603_1608Metric_Pad0.98x0.95mm_HandSolder |  | https://in.element14.com/yageo/rc0603fr-0722k1l/res-22k1-1-0-1w-0603-thick-film/dp/3495773RL | RC0603FR-0722K1L | SMD Chip Resistor, 5.1 kohm, ± 1%, 100 mW, 0603 [1608 Metric], Thick Film, General Purpose
R7 | 100K | Resistor_SMD:R_0603_1608Metric_Pad0.98x0.95mm_HandSolder |  | https://in.element14.com/panasonic/era3aeb104v/res-100k-0-1-0-1w-0603-metal-film/dp/1577632 | ERA3AEB104V | RES, 100K, 0.1%, 0.1W, 0603, METAL FILM
R9,R13 | 0R | Resistor_SMD:R_0603_1608Metric_Pad0.98x0.95mm_HandSolder |  | https://in.element14.com/yageo/ac0603jr-130rl/res-jumper-1a-thick-film-0603/dp/3951994 | AC0603JR-130RL | SMD Chip Resistor, 5.1 kohm, ± 1%, 100 mW, 0603 [1608 Metric], Thick Film, General Purpose
R11,R12,R14 | 120R | Resistor_SMD:R_0603_1608Metric_Pad0.98x0.95mm_HandSolder |  | https://in.element14.com/yageo/rc0603fr-13120rl/res-120r-1-0-1w-thick-film-0603/dp/4013297 | RC0603FR-13120RL | SMD Chip Resistor, 5.1 kohm, ± 1%, 100 mW, 0603 [1608 Metric], Thick Film, General Purpose
SW1 | SPST | Button_Switch_SMD:SW_DIP_SPSTx01_Slide_Copal_CHS-01A_W5.08mm_P1.27mm_JPin |  |  | CHS-01A | 1x DIP Switch, Single Pole Single Throw (SPST) switch, small symbol
U1 | MSMP0G3507 | VSSOP28_DGS_TEX |  | https://www.ti.com/product/MSPM0G3507/part-details/MSPM0G3507SDGS28R | MSPM0G3507SDGS28R | 80MHz Arm® Cortex®-M0+ MCU with 128KB flash 32KB SRAM 2x4Msps ADC, DAC, 3xCOMP, 2xOPA, CAN-FD, MATHA
U2 | TLV78533PDBVR | Package_TO_SOT_SMD:SOT-23-5_HandSoldering | https://www.ti.com/product/TLV785/part-details/TLV78533PDBVR |  | TLV78533PDBVR | 500mA high-PSRR low-Iq low-dropout regulator with enable
U3 | CP2102N | Package_DFN_QFN:QFN-24-1EP_4x4mm_P0.5mm_EP2.6x2.6mm_ThermalVias |  | https://in.element14.com/silicon-labs/cp2102n-a02-gqfn24r/usb-uart-bridge-40-to-85deg-c/dp/3387002 | CP2102N-A02-GQFN24R | USB to UART master bridge, QFN-24
U4 | TCAN3413DR | SOIC8_D_TEX |  | https://www.ti.com/product/TCAN3413/part-details/TCAN3413DR | TCAN3413DR | 3.3-V CAN FD transceiver with flexible IO and standby mode
Y1 | 8Mhz | Crystal:Crystal_SMD_Abracon_ABM3-2Pin_5.0x3.2mm |  | https://in.element14.com/abracon/abm3-8-000mhz-d2y-t/crystal-8mhz-18pf-smd/dp/2101329 | ABM3-8.000MHZ-D2Y-T | CRYSTAL, 8MHZ, 18PF, SMD

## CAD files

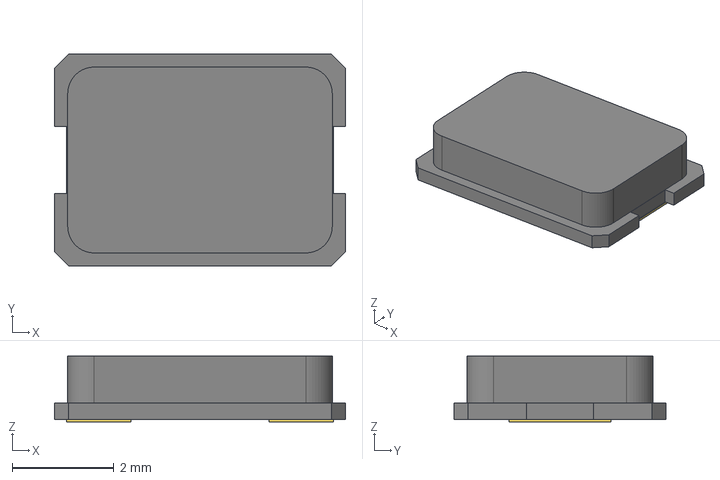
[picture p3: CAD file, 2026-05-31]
CANFD2USB_Hardware/References/CAD Data/ABM3-8-000MHZ-D2Y-T/XTAL_ABM3-8_000MHZ-D2Y-T_ABR.step
5.73 x 4.18 x 1.29 mm

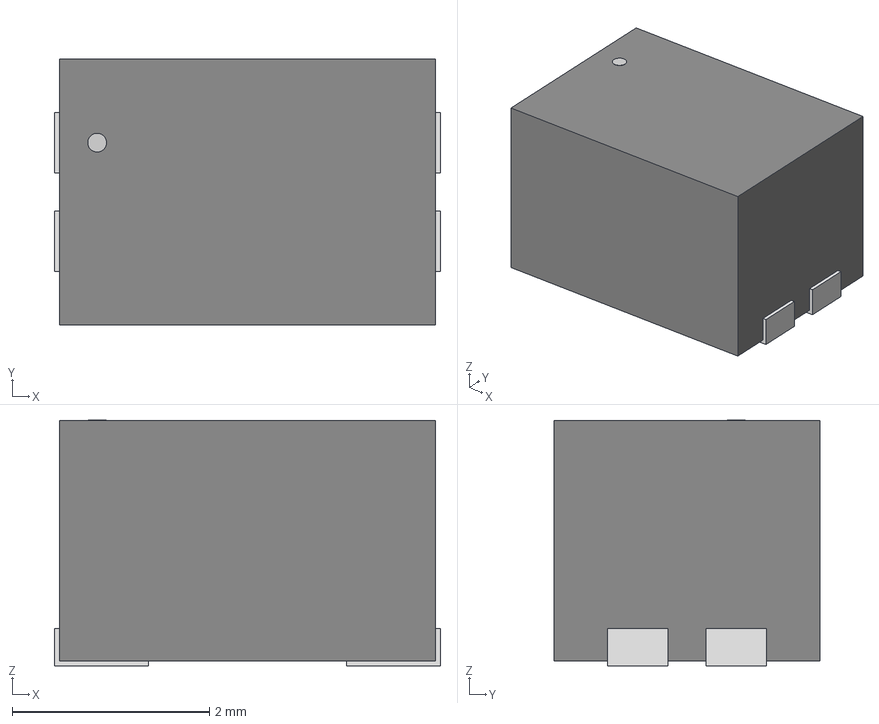
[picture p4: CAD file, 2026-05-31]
CANFD2USB_Hardware/References/CAD Data/ACT1210D/ACT1210_TDK.step
3.91 x 2.69 x 2.49 mm

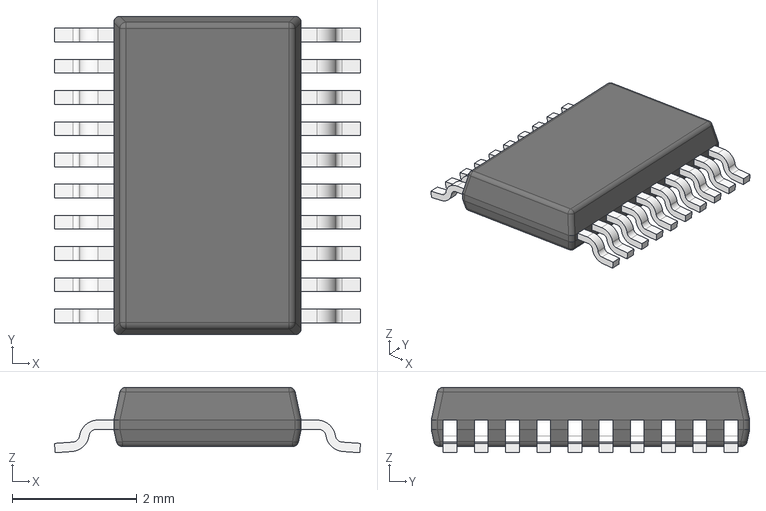
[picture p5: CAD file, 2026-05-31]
CANFD2USB_Hardware/References/CAD Data/MSPM0G3107/DGS0020A.stp
4.90 x 5.10 x 1.05 mm
BODY-VSSOP
LEAD-VSSOP x 20

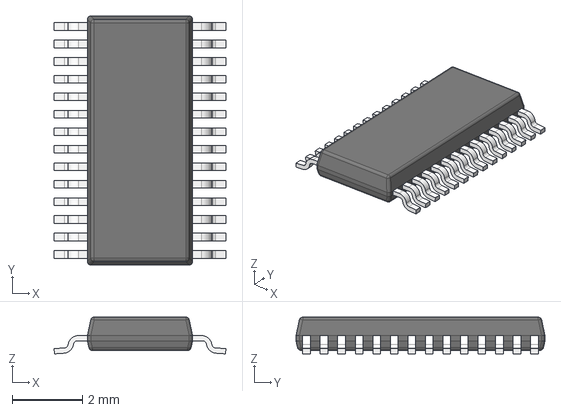
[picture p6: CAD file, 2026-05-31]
CANFD2USB_Hardware/References/CAD Data/MSPM0G3507/DGS0028A.stp
4.90 x 7.10 x 1.05 mm
BODY-VSSOP
LEAD-VSSOP x 28

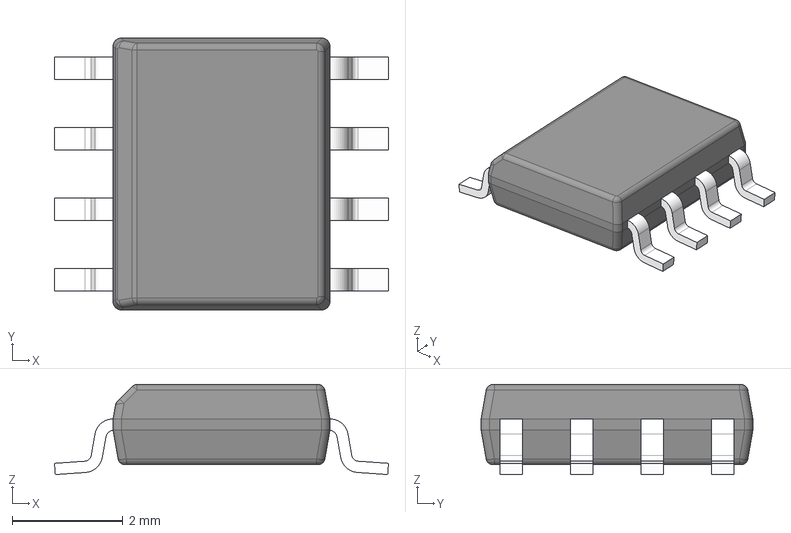
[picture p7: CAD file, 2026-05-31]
CANFD2USB_Hardware/References/CAD Data/TCAN3413DR/D0008A.stp
6.02 x 4.90 x 1.63 mm
BODY-SO
LEAD-D0008A x 8

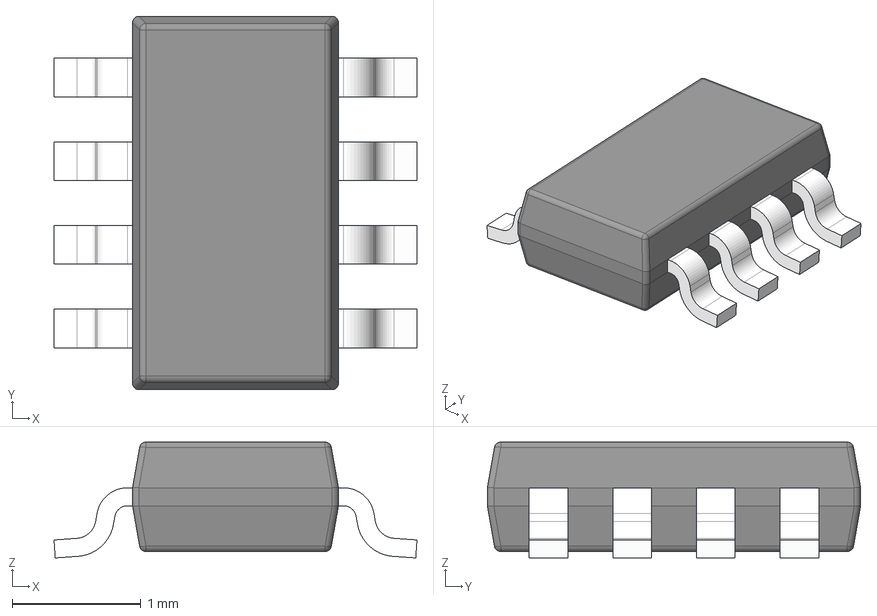
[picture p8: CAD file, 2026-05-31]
CANFD2USB_Hardware/References/CAD Data/TCAN3414/DDF0008A.stp
2.82 x 2.90 x 0.9 mm
BODY-SO
LEAD-SO x 8
PIN1-ID

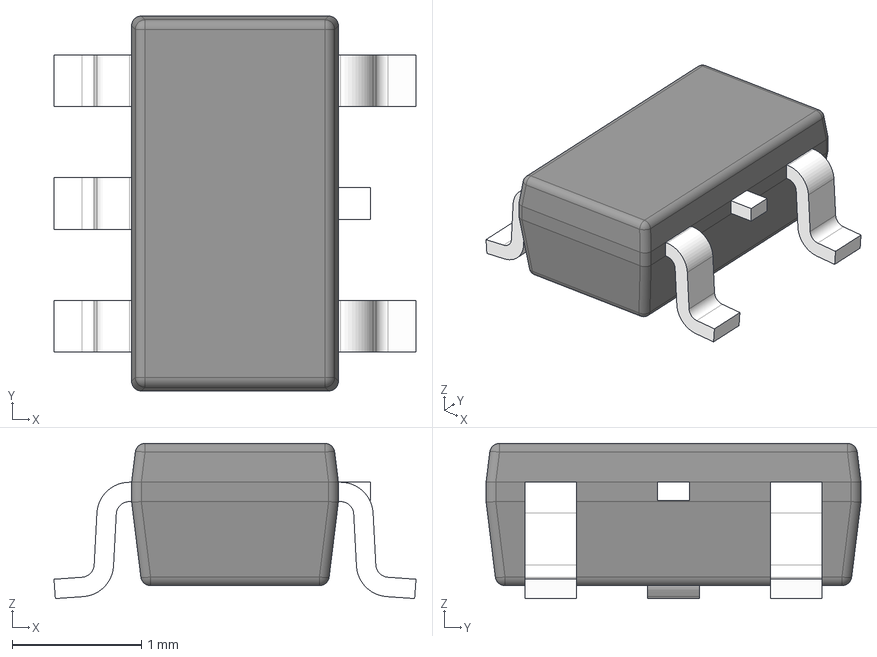
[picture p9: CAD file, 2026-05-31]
CANFD2USB_Hardware/References/CAD Data/TLV7853/DBV0005A.stp
2.80 x 2.90 x 1.20 mm
BODY-SOT
LEAD-SOT x 5
LEAD-DUMMY

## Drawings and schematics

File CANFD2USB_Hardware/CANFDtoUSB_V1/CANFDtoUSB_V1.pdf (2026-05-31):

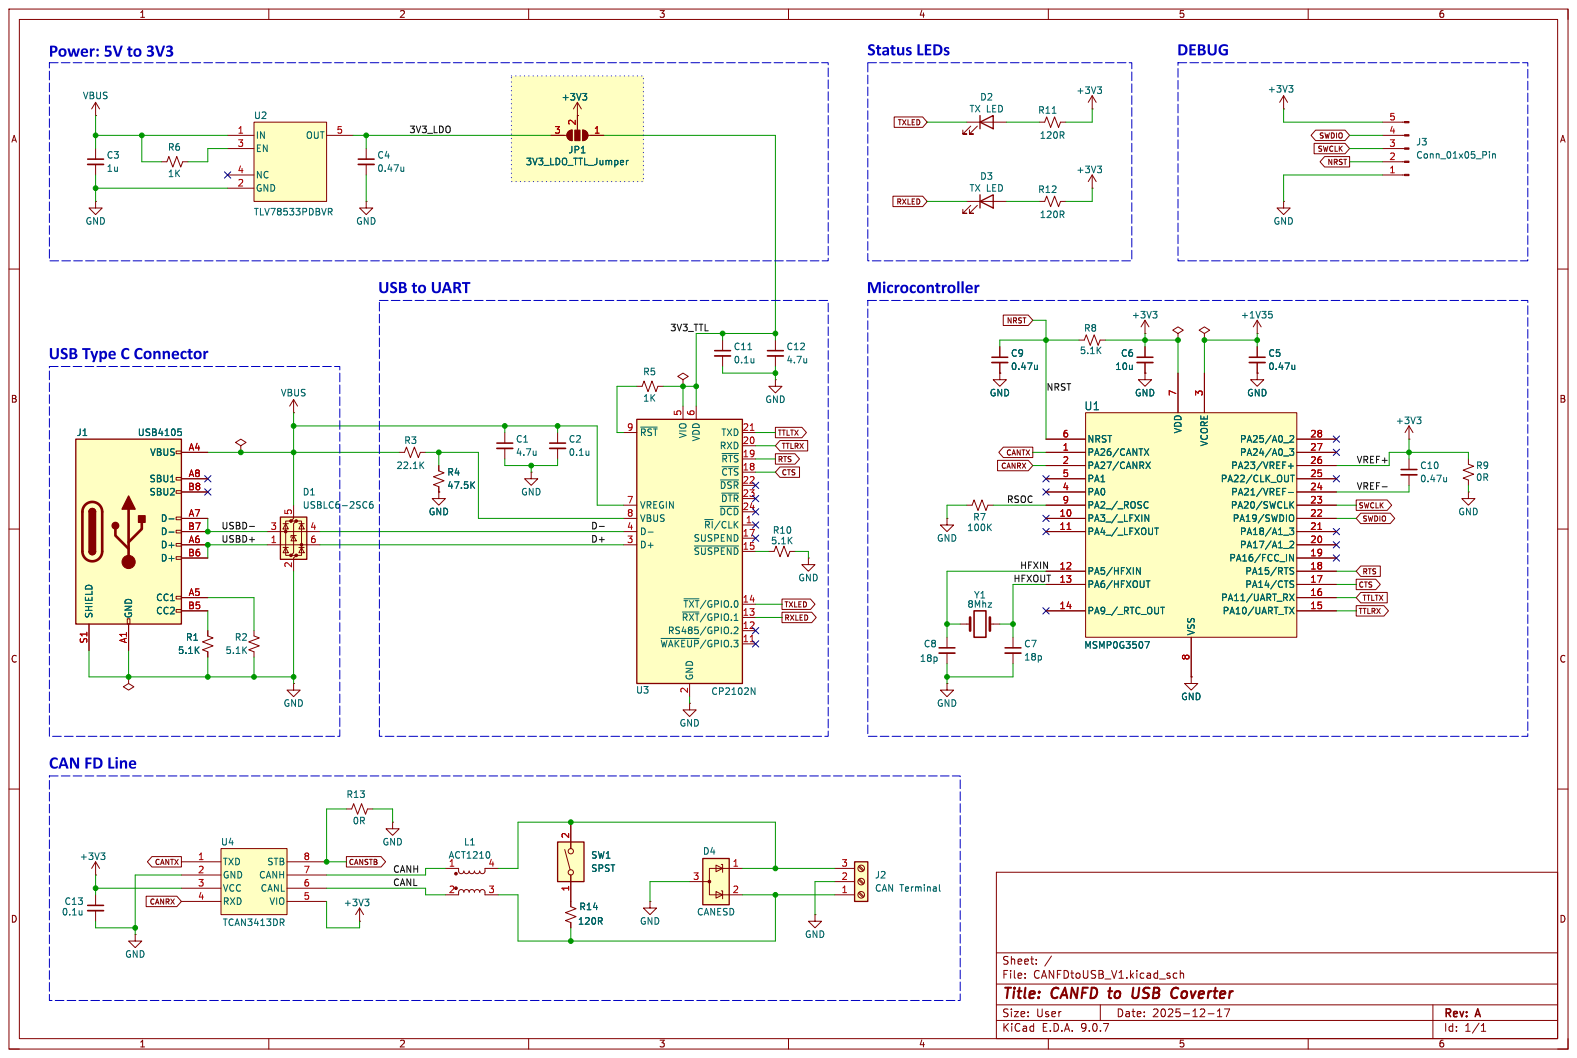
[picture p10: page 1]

3 PA25/A0_2 28 PA24/A0_3 27 PA20/SWCLK 23 PA19/SWDIO 22 PA18/A1_3 21 PA17/A1_2 20 PA26/CANTX 1 PA27/CANRX 2 PA4_/_LFXOUT 11 PA5/HFXIN 12 PA6/HFXOUT 13 PA9_/_RTC_OUT 14 VSS

8 PA23/VREF+ 26 PA22/CLK_OUT 25 PA21/VREF- 24 PA16/FCC_IN 19 PA15/RTS 18 PA14/CTS 17 PA11/UART_RX 16 PA10/UART_TX 15 U1 MSMP0G3507 GND

6 TXD 21 RXD 20 ~{RTS} 19 ~{CTS} 18 ~{DSR} 22 ~{DTR} 23 ~{DCD} 24 ~{RI}/CLK1 SUSPEND 17 ~{SUSPEND}15 ~{TXT}/GPIO.014 ~{RXT}/GPIO.113 RS485/GPIO.2 12 ~{WAKEUP}/GPIO.311 U3 CP2102N

VREF+ VREF- USBD- USBD+

8 PA23/VREF+ 26 PA22/CLK_OUT 25 PA21/VREF- 24 PA16/FCC_IN 19 PA15/RTS 18 PA14/CTS 17 PA11/UART_RX 16 PA10/UART_TX 15 GND

Id: 1/1 Title: CANFD to USB Coverter File: CANFDtoUSB_V1.kicad_sch Sheet: / GND

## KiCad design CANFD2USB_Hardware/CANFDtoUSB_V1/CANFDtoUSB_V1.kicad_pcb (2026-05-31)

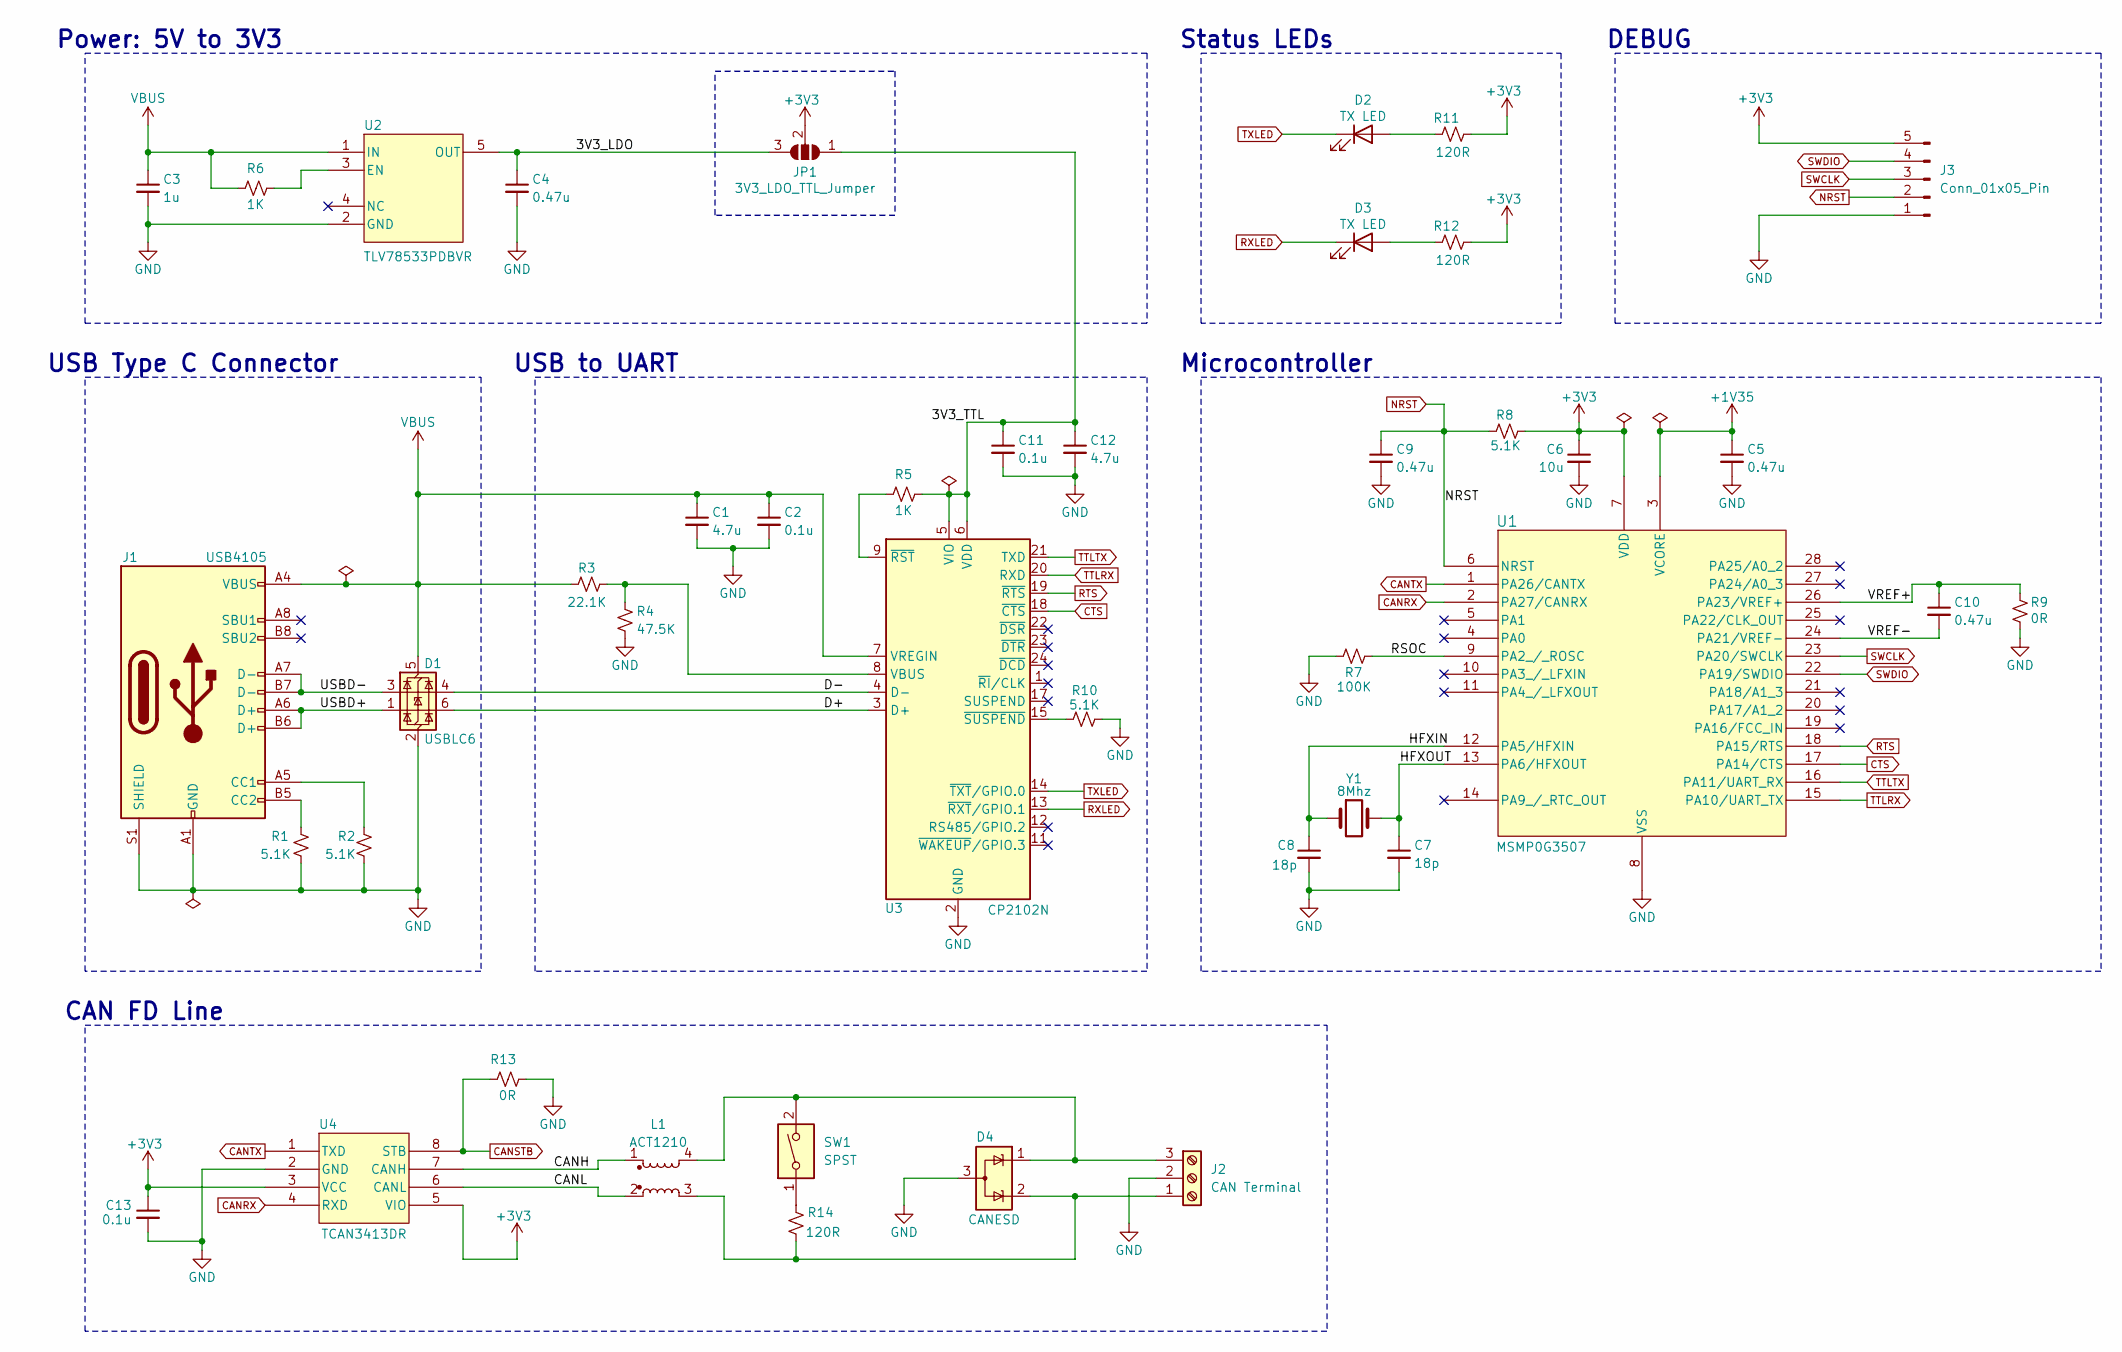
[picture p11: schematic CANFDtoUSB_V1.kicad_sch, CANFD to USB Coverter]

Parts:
C1, C12: 4.7u; C_0805_2012Metric_Pad1.18x1.45mm_HandSolder; Part Number GRM21BR71C475KE51K
C2, C11, C13: 0.1u; C_0603_1608Metric_Pad1.08x0.95mm_HandSolder; Part Number CC0603KPX7R7BB104
C3: 1u; C_0805_2012Metric_Pad1.18x1.45mm_HandSolder; Part Number CL21B105KOFNNNF
C4, C5, C9, C10: 0.47u; C_0603_1608Metric_Pad1.08x0.95mm_HandSolder; Part Number CL10B474KO8NNNC
C6: 10u; C_0805_2012Metric_Pad1.18x1.45mm_HandSolder; Part Number CL21A106KOQNNNF
C7, C8: 18p; C_0603_1608Metric_Pad1.08x0.95mm_HandSolder; Part Number CC0603GRNPO9BN180
D1: USBLC6; SOT-23-6; Part Number USBLC6-2P6
D2, D3: TX LED; LED_0603_1608Metric_Pad1.05x0.95mm_HandSolder; Part Number 19-217/BHC-ZL1M2RY/6T
D4: CANESD; SOT-323_SC-70; Part Number SP0502BAHTG
J1: USB4105; USB_C_Receptacle_GCT_USB4105-xx-A_16P_TopMnt_Horizontal; Part Number USB4105-GF-A-120
J2: CAN Terminal; TerminalBlock_Phoenix_PT-1,5-3-3.5-H_1x03_P3.50mm_Horizontal; Part Number YO0301500000G
J3: Conn_01x05_Pin; PinHeader_1x05_P2.54mm_Vertical
JP1: 3V3_LDO_TTL_Jumper; SolderJumper-3_P1.3mm_Open_RoundedPad1.0x1.5mm_NumberLabels
L1: ACT1210; ACT1210D-101-2P-TL00; Part Number ACT1210D-101-2P-TL00
R1, R2, R8, R10: 5.1K; R_0603_1608Metric_Pad0.98x0.95mm_HandSolder; Part Number RC0603FR-135K1L
R3: 22.1K; R_0603_1608Metric_Pad0.98x0.95mm_HandSolder; Part Number RC0603FR-0722K1L
R4: 47.5K; R_0603_1608Metric_Pad0.98x0.95mm_HandSolder; Part Number RC0603FR-0747K5L
R5, R6: 1K; R_0603_1608Metric_Pad0.98x0.95mm_HandSolder; Part Number RC0603FR-0722K1L
R7: 100K; R_0603_1608Metric_Pad0.98x0.95mm_HandSolder; Part Number ERA3AEB104V
R9, R13: 0R; R_0603_1608Metric_Pad0.98x0.95mm_HandSolder; Part Number AC0603JR-130RL
R11, R12, R14: 120R; R_0603_1608Metric_Pad0.98x0.95mm_HandSolder; Part Number RC0603FR-13120RL
SW1: SPST; SW_DIP_SPSTx01_Slide_Copal_CHS-01A_W5.08mm_P1.27mm_JPin; Part Number CHS-01A
U1: MSMP0G3507; VSSOP28_DGS_TEX; Part Number MSPM0G3507SDGS28R
U2: TLV78533PDBVR; SOT-23-5_HandSoldering; Part Number TLV78533PDBVR
U3: CP2102N; QFN-24-1EP_4x4mm_P0.5mm_EP2.6x2.6mm_ThermalVias; Part Number CP2102N-A02-GQFN24R
U4: TCAN3413DR; SOIC8_D_TEX; Part Number TCAN3413DR
Y1: 8Mhz; Crystal_SMD_Abracon_ABM3-2Pin_5.0x3.2mm; Part Number ABM3-8.000MHZ-D2Y-T

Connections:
+1V35: C5.1, U1.3 (VCORE)
+3V3: C6.1, C13.1, J3.5, JP1.2 (C), R8.2, R11.2, R12.2, U1.7 (VDD), U4.3 (VCC), U4.5 (VIO)
/3V3_LDO: C4.1, JP1.3 (B), U2.5 (OUT)
/3V3_TTL: C11.1, C12.1, JP1.1 (A), R5.2, U3.5 (VIO), U3.6 (VDD)
/CANH: L1.1, U4.7 (CANH)
/CANL: L1.2, U4.6 (CANL)
/D+: D1.6 (I/O1), U3.3 (D+)
/D-: D1.4 (I/O2), U3.4 (D-)
/HFXIN: C8.1, U1.12 (PA5/HFXIN), Y1.1
/HFXOUT: C7.1, U1.13 (PA6/HFXOUT), Y1.2
/RSOC: R7.2, U1.9 (PA2_/_ROSC)
/USBD+: D1.1 (I/O1), J1.A6 (D+), J1.B6 (D+)
/USBD-: D1.3 (I/O2), J1.A7 (D-), J1.B7 (D-)
/VREF+: C10.1, R9.2, U1.26 (PA23/VREF+)
/VREF-: C10.2, U1.24 (PA21/VREF-)
CANRX: U1.2 (PA27/CANRX), U4.4 (RXD)
CANSTB: R13.1, U4.8 (STB)
CANTX: U1.1 (PA26/CANTX), U4.1 (TXD)
CTS: U1.17 (PA14/CTS), U3.18 (~CTS)
GND: C1.2, C2.2, C3.2, C4.2, C5.2, C6.2, C7.2, C8.2, C9.2, C11.2, C12.2, C13.2, D1.2 (GND), D4.3 (A), J1.A1 (GND), J1.A12 (GND), J1.B1 (GND), J1.B12 (GND), J1.S1 (SHIELD), J2.2, J3.1, R1.2, R2.2, R4.2, R7.1, R9.1, R10.2, R13.2, U1.8 (VSS), U2.2 (GND), U3.2 (GND), U3.25 (GND), U4.2 (GND)
NRST: C9.1, J3.2, R8.1, U1.6 (NRST)
unnamed: D2.2 (A), R11.1
unnamed: D3.2 (A), R12.1
unnamed: J1.A5 (CC1), R2.1
unnamed: J1.B5 (CC2), R1.1
unnamed: D4.2 (K), J2.1, L1.3, R14.2
unnamed: D4.1 (K), J2.3, L1.4, SW1.2
unnamed: R14.1, SW1.1
unnamed: R6.2, U2.3 (EN)
unnamed: R3.2, R4.1, U3.8 (VBUS)
unnamed: R5.1, U3.9 (~RST)
unnamed: R10.1, U3.15 (~SUSPEND)
RTS: U1.18 (PA15/RTS), U3.19 (~RTS)
RXLED: D3.1 (K), U3.13 (~RXT/GPIO.1)
SWCLK: J3.3, U1.23 (PA20/SWCLK)
SWDIO: J3.4, U1.22 (PA19/SWDIO)
TTLRX: U1.15 (PA10/UART_TX), U3.20 (RXD)
TTLTX: U1.16 (PA11/UART_RX), U3.21 (TXD)
TXLED: D2.1 (K), U3.14 (~TXT/GPIO.0)
VBUS: C1.1, C2.1, C3.1, D1.5 (VBUS), J1.A4 (VBUS), J1.A9 (VBUS), J1.B4 (VBUS), J1.B9 (VBUS), R3.1, R6.1, U2.1 (IN), U3.7 (VREGIN)

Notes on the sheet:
Microcontroller
USB to UART
DEBUG
Power: 5V to 3V3
Status LEDs
CAN FD Line
USB Type C Connector

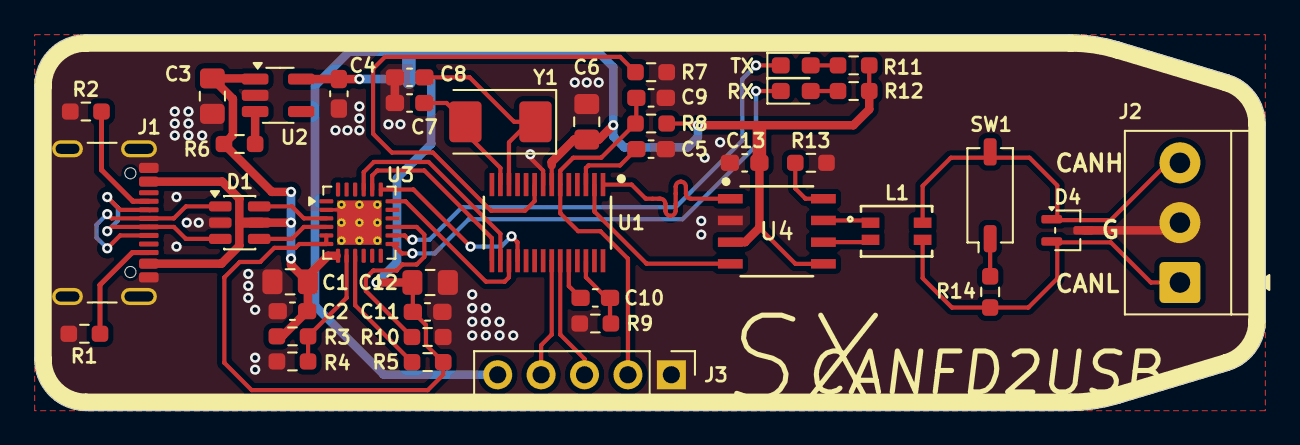
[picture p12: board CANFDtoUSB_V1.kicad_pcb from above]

Board: 2 copper layers, 72.0 x 22.0 mm, 42 parts (1 on the bottom side), 40 nets.

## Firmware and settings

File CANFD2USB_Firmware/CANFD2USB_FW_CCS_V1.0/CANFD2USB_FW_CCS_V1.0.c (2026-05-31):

#include "ti_msp_dl_config.h"
#include <string.h>
#include <stdint.h>
#include <stdbool.h>

// ── CANtrace wire protocol ────────────────────────────────────────────────────
#define SOF        0xAA
#define EOF_BYTE   0x55
#define FRAME_SIZE 73

#define FLAG_ERR   0x20   // error frame — avoids clash with ESI (0x10)
#define FLAG_ACK   0x40   // TX success confirmation back to PC

// ── CPU / CAN timing ──────────────────────────────────────────────────────────
#define CPU_FREQ_HZ            32000000UL    // 80 MHz (MSPM0G3507)
#define CAN_FRAME_BITS         130UL       // worst-case classic CAN frame bits
#define CAN_FD_BITS            200UL       // worst-case CAN FD frame bits
#define ACK_TIMEOUT_MULTIPLIER 3UL         // 3× safety margin (automotive standard)

// Set these to match your SYSCFG_DL_MCAN0_init() configuration
#define MCAN_NOMINAL_BITRATE_BPS   500000UL
#define MCAN_DATA_BITRATE_BPS      2000000UL

// ── Compute ACK timeout cycles based on bitrate ───────────────────────────────
// Formula: multiplier × bits × (CPU_freq / bitrate)
static uint32_t can_ack_timeout_cycles(uint32_t bitrate_bps, bool is_fd)
{
    uint32_t bits = is_fd ? CAN_FD_BITS : CAN_FRAME_BITS;
    // Avoid overflow: compute (CPU_FREQ / bitrate) first, then multiply
    // At 32MHz / 500kbps = 64 cycles per bit
    uint32_t cycles_per_bit = CPU_FREQ_HZ / bitrate_bps;
    return ACK_TIMEOUT_MULTIPLIER * bits * cycles_per_bit;
}

// ── UART TX ───────────────────────────────────────────────────────────────────
static void uart_write_byte(uint8_t b)
{
    while (DL_UART_Main_isBusy(UART_0_INST));
    DL_UART_Main_transmitData(UART_0_INST, b);
}

// ── DLC to actual byte count ──────────────────────────────────────────────────
static uint8_t dlc_to_len(uint8_t dlc)
{
    static const uint8_t table[] =
        {0,1,2,3,4,5,6,7,8,12,16,20,24,32,48,64};
    return (dlc < 16) ? table[dlc] : 64;
}

// ── Send normal CAN frame to CANtrace (RX path) ───────────────────────────────
static void send_cantrace_frame(uint32_t id, uint8_t dlc,
                                uint8_t *data, uint8_t dataLen,
                                bool ext, bool fd, bool brs)
{
    uint8_t buf[FRAME_SIZE];
    memset(buf, 0x00, FRAME_SIZE);

    buf[0] = SOF;
    buf[1] = (id)       & 0xFF;
    buf[2] = (id >>  8) & 0xFF;
    buf[3] = (id >> 16) & 0xFF;
    buf[4] = (id >> 24) & 0xFF;
    buf[5] = (ext ? 0x01 : 0x00)
           | (fd  ? 0x04 : 0x00)
           | (brs ? 0x08 : 0x00);
    buf[6] = dlc;
    buf[7] = dataLen;

    uint8_t len = (dataLen > 64) ? 64 : dataLen;
    for (uint8_t i = 0; i < len; i++)
        buf[8 + i] = data[i];

    buf[FRAME_SIZE - 1] = EOF_BYTE;

    for (int i = 0; i < FRAME_SIZE; i++)
        uart_write_byte(buf[i]);
}

// ── Send TX-ACK frame to CANtrace (TX success) ────────────────────────────────
static void send_cantrace_ack_frame(uint32_t id, uint8_t dlc,
                                    uint8_t *data, uint8_t dataLen,
                                    bool ext, bool fd, bool brs)
{
    uint8_t buf[FRAME_SIZE];
    memset(buf, 0x00, FRAME_SIZE);

    buf[0] = SOF;
    buf[1] = (id)       & 0xFF;
    buf[2] = (id >>  8) & 0xFF;
    buf[3] = (id >> 16) & 0xFF;
    buf[4] = (id >> 24) & 0xFF;
    buf[5] = FLAG_ACK
           | (ext ? 0x01 : 0x00)
           | (fd  ? 0x04 : 0x00)
           | (brs ? 0x08 : 0x00);
    buf[6] = dlc;
    buf[7] = dataLen;

    uint8_t len = (dataLen > 64) ? 64 : dataLen;
    for (uint8_t i = 0; i < len; i++)
        buf[8 + i] = data[i];

    buf[FRAME_SIZE - 1] = EOF_BYTE;

    for (int i = 0; i < FRAME_SIZE; i++)
        uart_write_byte(buf[i]);
}

// ── Send error frame to CANtrace (TX failure) ─────────────────────────────────
// errType (MCAN PSR LEC):
//   1 = Stuff Error
//   2 = Form Error
//   3 = ACK Error
//   4 = Bit1 Error
//   5 = Bit0 Error
//   6 = CRC Error
static void send_cantrace_error_frame(uint8_t errType)
{
    uint8_t buf[FRAME_SIZE];
    memset(buf, 0x00, FRAME_SIZE);
    buf[0] = SOF;
    buf[5] = FLAG_ERR;
    buf[6] = errType;
    buf[FRAME_SIZE - 1] = EOF_BYTE;
    for (int i = 0; i < FRAME_SIZE; i++)
        uart_write_byte(buf[i]);
}

// ── RX state machine ──────────────────────────────────────────────────────────
static uint8_t  s_txBuf[FRAME_SIZE];
static uint8_t  s_txIdx   = 0;
static bool     s_inFrame = false;

static void process_uart_rx(void)
{
    uint8_t b;

    while (!DL_UART_Main_isRXFIFOEmpty(UART_0_INST))
    {
        b = DL_UART_Main_receiveData(UART_0_INST);

        if (!s_inFrame) {
            if (b == SOF) {
                s_txBuf[0] = b;
                s_txIdx    = 1;
                s_inFrame  = true;
            }
        } else {
            s_txBuf[s_txIdx++] = b;

            if (s_txIdx >= FRAME_SIZE) {
                s_inFrame = false;
                s_txIdx   = 0;

                // Validate EOF
                if (s_txBuf[FRAME_SIZE - 1] != EOF_BYTE)
                    return;

                // Parse fields
                uint32_t id = ((uint32_t)s_txBuf[1])
                            | ((uint32_t)s_txBuf[2] <<  8)
                            | ((uint32_t)s_txBuf[3] << 16)
                            | ((uint32_t)s_txBuf[4] << 24);

                uint8_t flags = s_txBuf[5];
                bool ext      = (flags & 0x01) != 0;
                bool fd       = (flags & 0x04) != 0;
                bool brs      = (flags & 0x08) != 0;
                uint8_t dlc   = s_txBuf[6] & 0x0F;
                uint8_t dlen  = s_txBuf[7];

                // Build MCAN TX element
                DL_MCAN_TxBufElement tx;
                memset(&tx, 0, sizeof(tx));
                tx.id  = ext ? id : (id << 18U);
                tx.xtd = ext ? 1U : 0U;
                tx.rtr = 0U;
                tx.fdf = fd  ? 1U : 0U;
                tx.brs = brs ? 1U : 0U;
                tx.dlc = dlc;
                tx.esi = 0U;
                tx.efc = 0U;
                tx.mm  = 0U;

                uint8_t len = (dlen > 64) ? 64 : dlen;
                for (uint8_t i = 0; i < len; i++)
                    tx.data[i] = s_txBuf[8 + i];

                // Transmit
                DL_MCAN_writeMsgRam(MCAN0_INST,
                                    DL_MCAN_MEM_TYPE_BUF, 0, &tx);
                DL_MCAN_TXBufAddReq(MCAN0_INST, 0U);

                // ── Automotive-grade ACK timeout ──────────────────────────────
                // 3× worst-case frame time at nominal bitrate
                // Classic CAN: 130 bits / bitrate × 3
                // CAN FD:      200 bits / bitrate × 3
                uint32_t timeout = can_ack_timeout_cycles(
                                       MCAN_NOMINAL_BITRATE_BPS, fd);

                while (timeout--) {
                    if (!(DL_MCAN_getTxBufReqPend(MCAN0_INST) & 0x1))
                        break;
                }

                // ── Sample result ONCE — one status per message ───────────────
                DL_MCAN_ProtocolStatus ps;
                DL_MCAN_getProtocolStatus(MCAN0_INST, &ps);

                if (ps.lastErrCode != 0 && ps.lastErrCode != 7) {
                    // TX failed — report error
                    send_cantrace_error_frame((uint8_t)ps.lastErrCode);
                } else {
                    // TX succeeded — confirm to PC
                    send_cantrace_ack_frame(id, dlc,
                                            s_txBuf + 8, dlen,
                                            ext, fd, brs);
                }
            }
        }
    }
}

// ── Main ──────────────────────────────────────────────────────────────────────
int main(void)
{
    SYSCFG_DL_init();

    // Startup delay
    volatile uint32_t d = 200000;
    while (d--);

    // Force MCAN clean init
    DL_MCAN_setOpMode(MCAN0_INST, DL_MCAN_OPERATION_MODE_SW_INIT);
    while (DL_MCAN_OPERATION_MODE_SW_INIT != DL_MCAN_getOpMode(MCAN0_INST));

    SYSCFG_DL_MCAN0_init();

    DL_MCAN_setOpMode(MCAN0_INST, DL_MCAN_OPERATION_MODE_NORMAL);
    while (DL_MCAN_OPERATION_MODE_NORMAL != DL_MCAN_getOpMode(MCAN0_INST));

    while (1)
    {
        // ── Process incoming UART → CAN TX requests from PC ───────────────────
        process_uart_rx();

        // ── Forward received CAN frames to CANtrace ───────────────────────────
        DL_MCAN_RxFIFOStatus status;
        status.num = DL_MCAN_RX_FIFO_NUM_0;
        DL_MCAN_getRxFIFOStatus(MCAN0_INST, &status);

        while (status.fillLvl > 0)
        {
            DL_MCAN_RxBufElement rx;
            memset(&rx, 0, sizeof(rx));

            uint32_t getIdx = status.getIdx;

            DL_MCAN_readMsgRam(MCAN0_INST,
                               DL_MCAN_MEM_TYPE_FIFO,
                               0,
                               DL_MCAN_RX_FIFO_NUM_0,
                               &rx);

            DL_MCAN_writeRxFIFOAck(MCAN0_INST,
                                   DL_MCAN_RX_FIFO_NUM_0,
                                   getIdx);

            bool     ext     = (rx.xtd == 1U);
            bool     fd      = (rx.fdf == 1U);
            bool     brs     = (rx.brs == 1U);
            uint8_t  dlc     = (uint8_t)rx.dlc;
            uint8_t  dataLen = dlc_to_len(dlc);
            uint32_t id      = ext ? rx.id : ((rx.id >> 18U) & 0x7FFU);

            send_cantrace_frame(id, dlc,
                                (uint8_t *)rx.data, dataLen,
                                ext, fd, brs);

            status.num = DL_MCAN_RX_FIFO_NUM_0;
            DL_MCAN_getRxFIFOStatus(MCAN0_INST, &status);
        }
    }
}

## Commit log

2026-05-31 Initial commit — README, licenses, folder structure
2026-05-31 Add hardware, firmware, and software source files
    [ACT1210_TDK.step, CANFD2USBV1.0_BOM-JLCPCB.xls, CANFD2USBV1.0_bom.csv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]
